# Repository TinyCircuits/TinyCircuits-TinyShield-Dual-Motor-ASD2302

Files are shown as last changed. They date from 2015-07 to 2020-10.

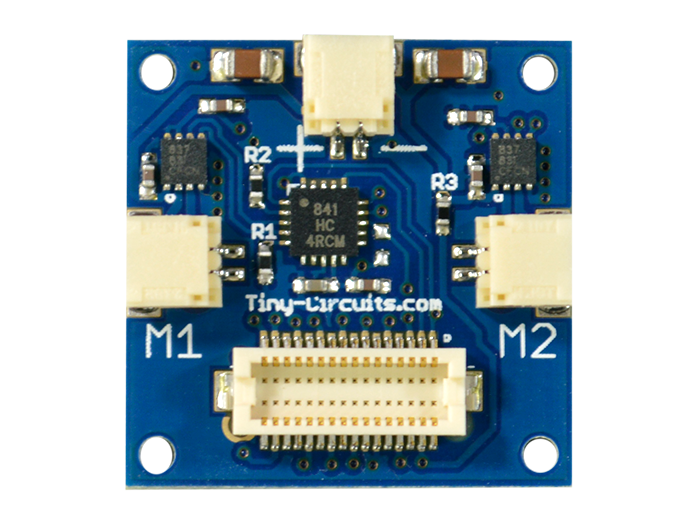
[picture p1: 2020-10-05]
images/ASD2302-R-Tutorial-Image-01.png

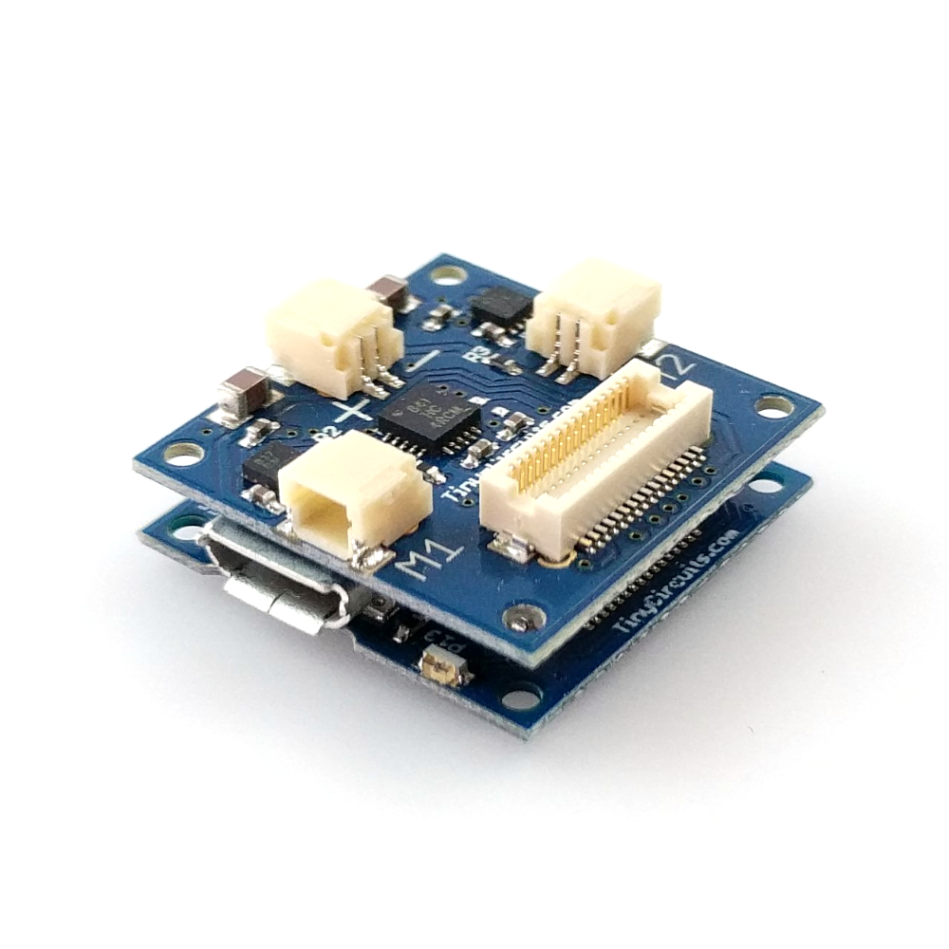
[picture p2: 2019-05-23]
images/ASD2302-R-Tutorial-Image-03.jpg

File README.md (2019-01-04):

# TinyCircuits TinyShield Dual Motor Board
# ASD2302 Rev3

The design files are located under design_files/ for the TinyCircuits ASD2302 Rev 3 PCB.  This is a TinyShield board (Square Version, 20mm x 20mm) that has a two TI DRV8847 motor drivers on it, to allow two DC brushed motors to be driven.

Format is in Cadsoft Eagle format - Eagle version 6.2 was used for the original design.

For more infomation on this, check out the product page at TinyCircuits.com:  https://tinycircuits.com/collections/motors/products/dual-motor-tinyshield

# License:

Design by TinyCircuits.
All design files are released under the Creative Commons Attribution Share-Alike 3.0 License, see the following link for details: http://creativecommons.org/licenses/by-sa/3.0

All text above must be included in any redistribution or derived design

This project uses designs and concepts developed as part of the Arduino project and the LilyPad project.  The TinyCircuits design files themselves (schematics, PCB and libraries) are not directly derived from these works' design files and have been created new, however the concepts and basic architecture behind the TinyDuino and TinyLily products are derived and we thank the hard work of the organizations below for their contributions to open-source hardware:
  
Original Arduino Uno Design by Team Arduino

LilyPad Arduino Design by Leah Buechley and Sparkfun Electronics

Please support the open-source hardware community

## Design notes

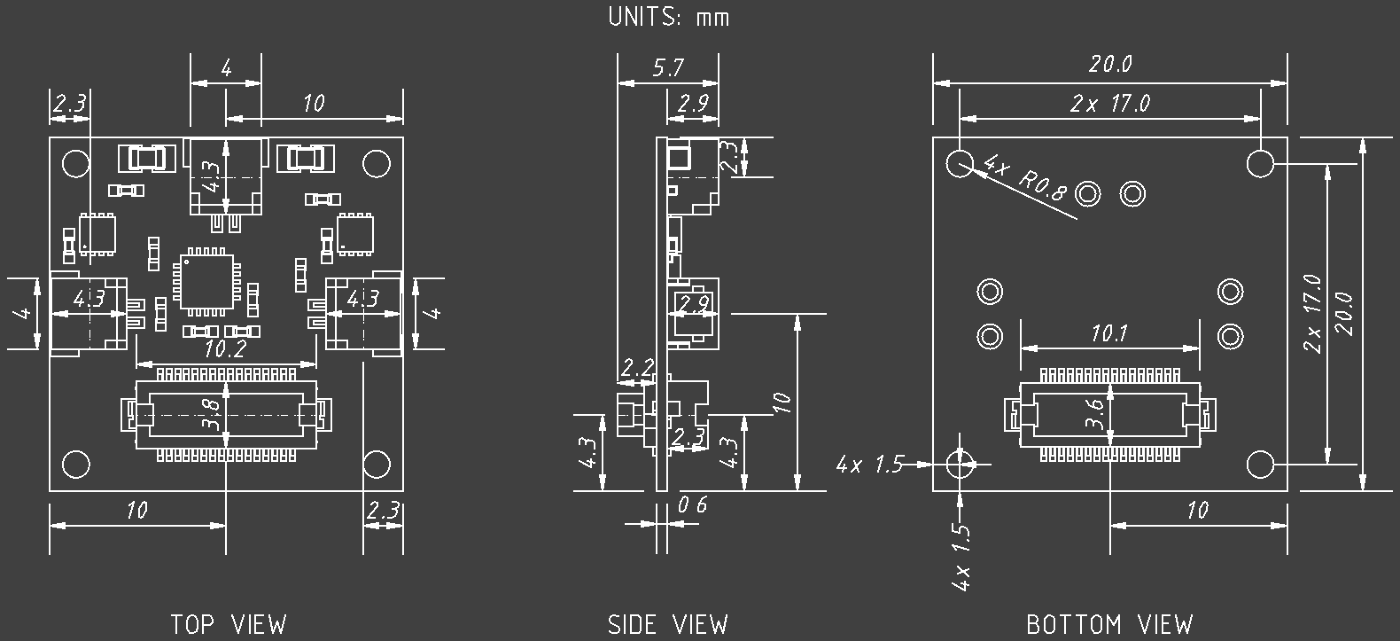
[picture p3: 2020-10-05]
cad/TinyShield_DUAL_MOTOR_ASD2302_REV3-DETAILED_DRAWING_COMPACT-PNG.png

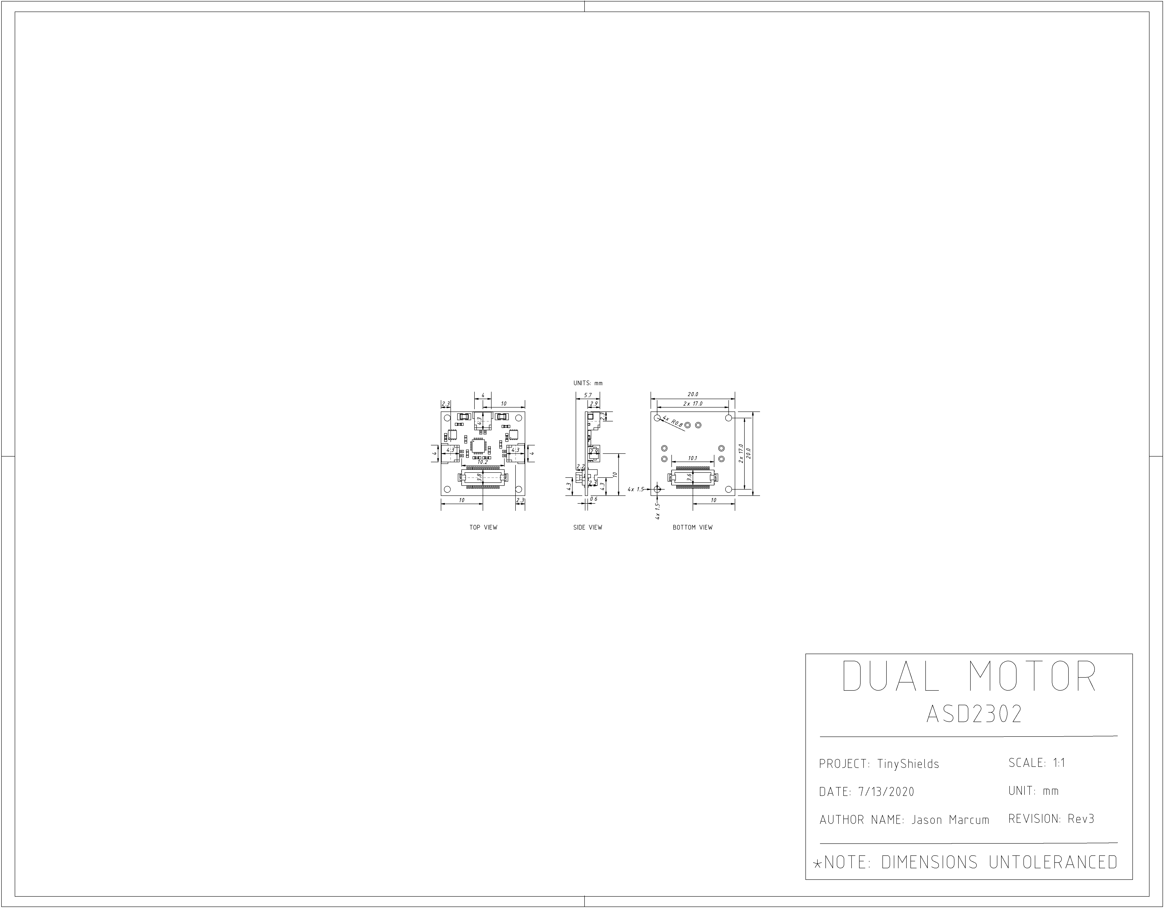
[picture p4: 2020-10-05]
cad/TinyShield_DUAL_MOTOR_ASD2302_REV3-DETAILED_DRAWING-PNG.png

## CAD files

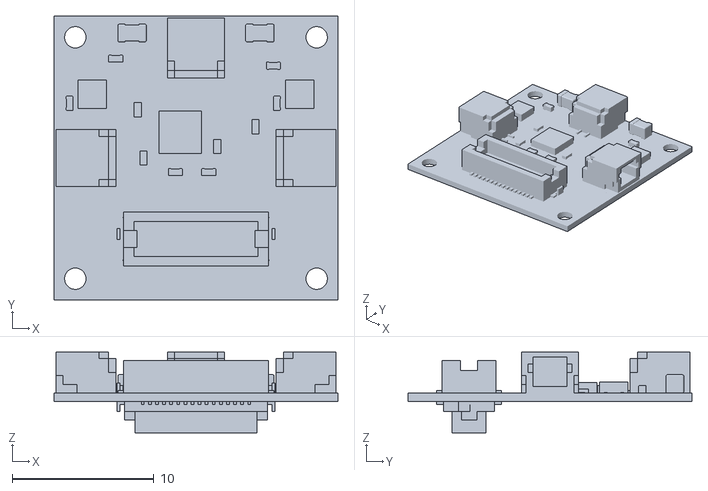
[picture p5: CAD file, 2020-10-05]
cad/TinyShield_MOTOR_STL_ASD2302_REV3-STL.stl
20.0 x 20.0 x 5.69

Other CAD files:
cad/TinyShield_DUAL_MOTOR_ASD2302_REV3-DETAILED_DRAWING-DXF.dxf

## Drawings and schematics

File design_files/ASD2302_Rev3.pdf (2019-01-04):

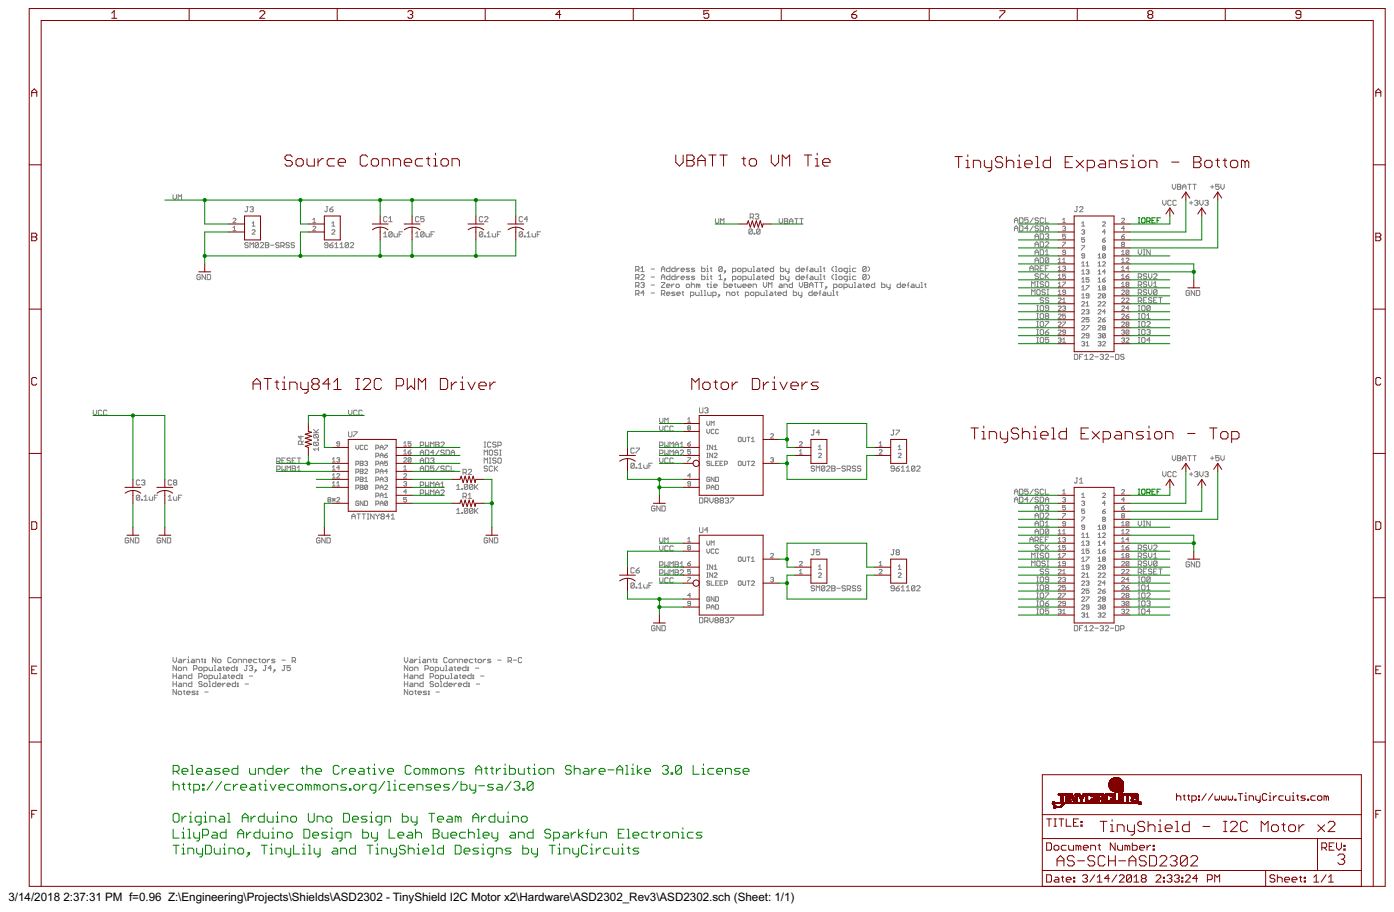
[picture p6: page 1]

3/14/2018 2:37:31 PM f=0.96 Z:\Engineering\Projects\Shields\ASD2302 - TinyShield I2C Motor x2\Hardware\ASD2302_Rev3\ASD2302.sch (Sheet: 1/1)

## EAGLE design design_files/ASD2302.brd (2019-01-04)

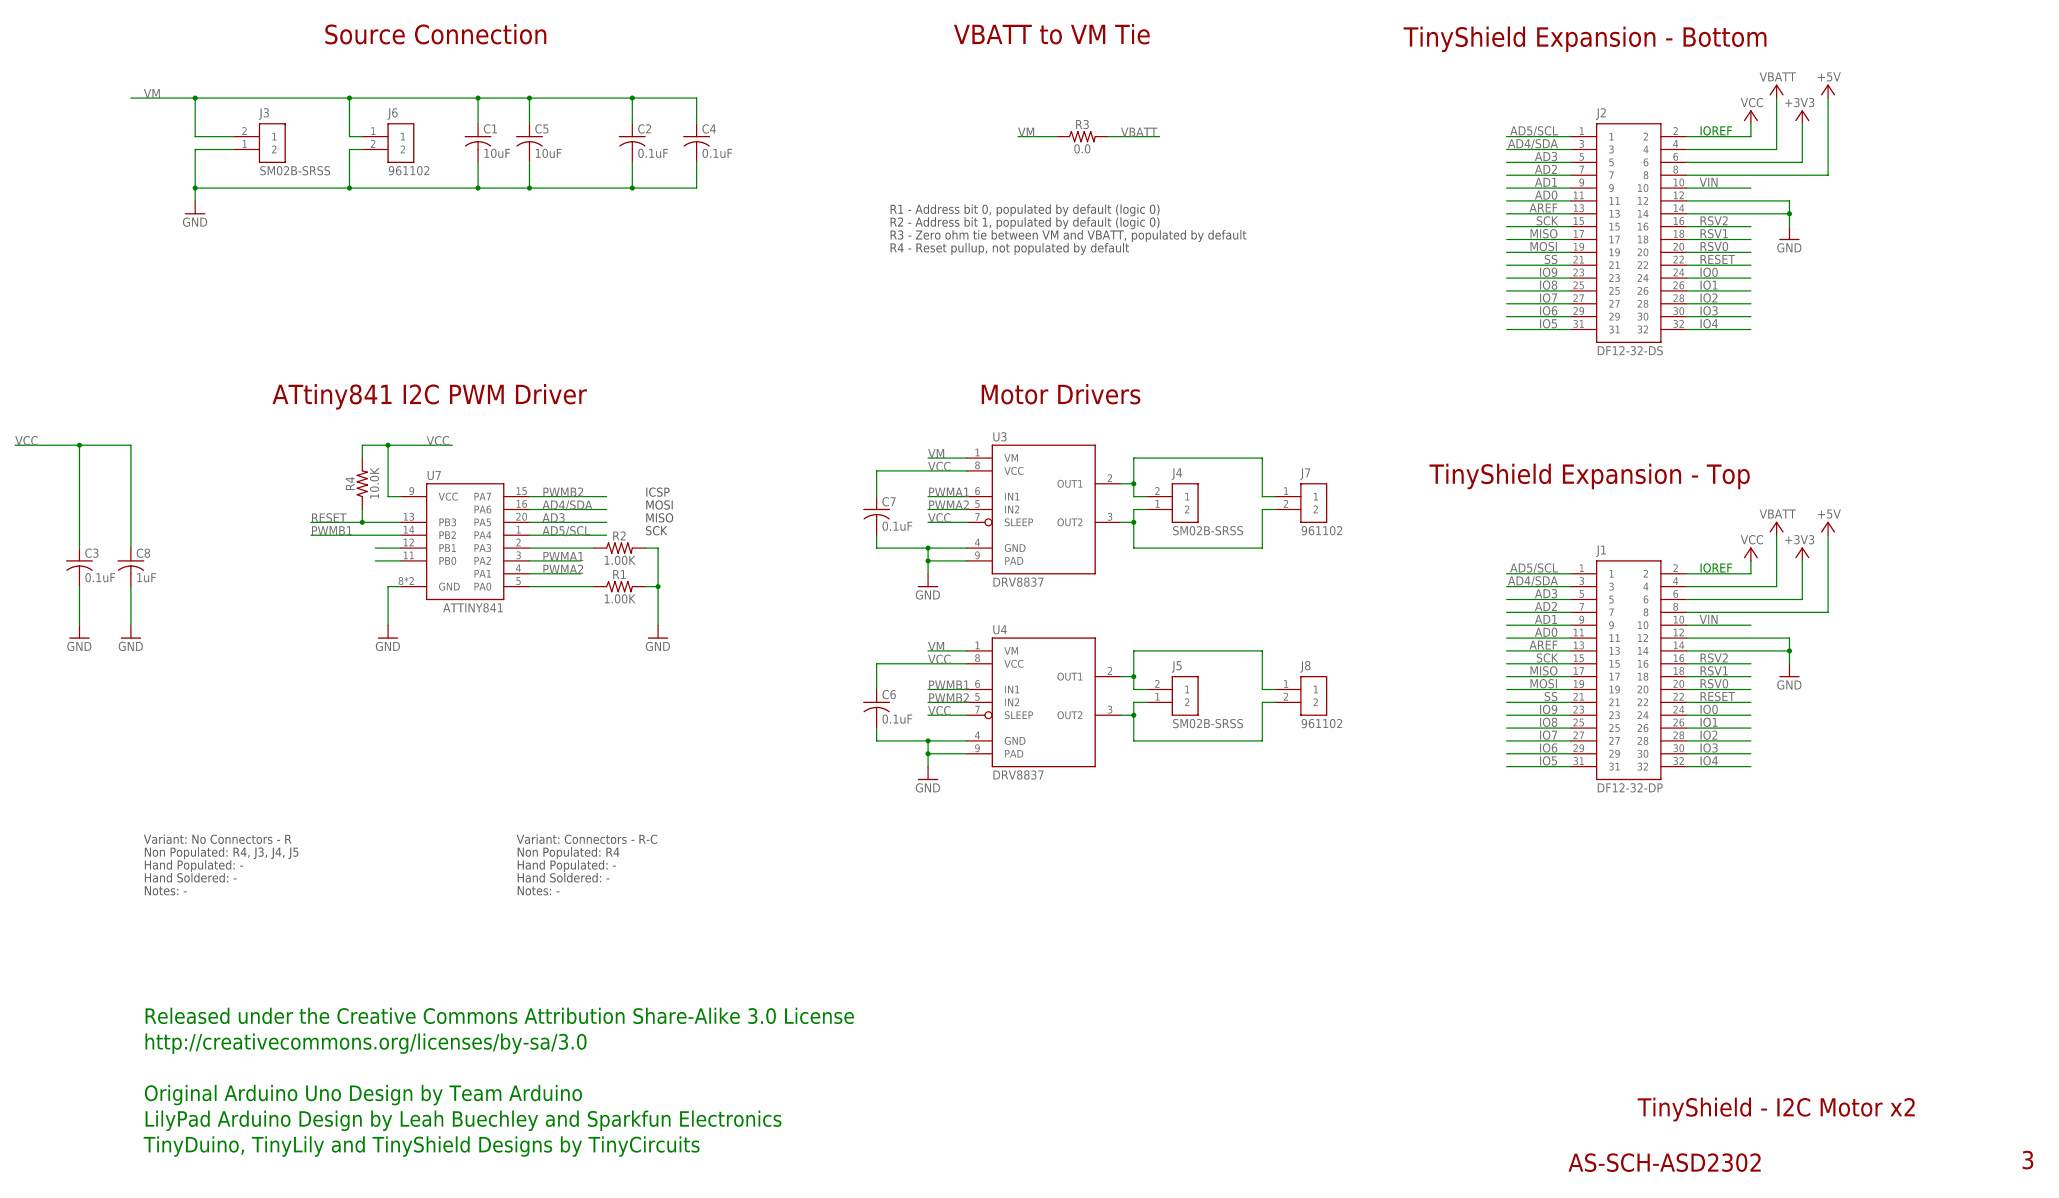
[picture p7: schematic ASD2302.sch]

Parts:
C1, C5: 10uF; C0805
C2: 0.1uF; C0402
C3, C4, C6, C7: 0.1uF; C0402; PARTNO AS-ITM-00008
C8: 1uF; C0402; PARTNO AS-ITM-00105
J1: DF12-32-DP; PARTNO AS-ITM-00015
J2: DF12-32-DS; PARTNO AS-ITM-00012
J3, J4, J5: SM02B-SRSS; JST_SH_2X1
J6, J7, J8: 961102; 2X.1"
R1, R2: 1.00K; 0402; PARTNO AS-ITM-00003
R3: 0.0; 0402
R4: 10.0K; 0402
U3, U4: DRV8837; WSON-8
U7: ATTINY841; VQFN-20

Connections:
+3V3: J1.6, J2.6
+5V: J1.8, J2.8
AD0: J1.11, J2.11
AD1: J1.9, J2.9
AD2: J1.7, J2.7
AD3: J1.5, J2.5, U7.20 (PA5)
AD4/SDA: J1.3, J2.3, U7.16 (PA6)
AD5/SCL: J1.1, J2.1, U7.1 (PA4)
AREF: J1.13, J2.13
GND: C1.2, C2.2, C3.2, C4.2, C5.2, C6.2, C7.2, C8.2, J1.12, J1.14, J2.12, J2.14, J3.1 (2), J6.2, R1.2, R2.2, U3.4 (GND), U3.9 (PAD), U4.4 (GND), U4.9 (PAD), U7.8 (GND), U7.PAD (GND)
IO0: J1.24, J2.24
IO1: J1.26, J2.26
IO2: J1.28, J2.28
IO3: J1.30, J2.30
IO4: J1.32, J2.32
IO5: J1.31, J2.31
IO6: J1.29, J2.29
IO7: J1.27, J2.27
IO8: J1.25, J2.25
IO9: J1.23, J2.23
MISO: J1.17, J2.17
MOSI: J1.19, J2.19
unnamed: J5.1 (2), J8.2, U4.3 (OUT2)
unnamed: J5.2 (1), J8.1, U4.2 (OUT1)
unnamed: J4.2 (1), J7.1, U3.2 (OUT1)
unnamed: J4.1 (2), J7.2, U3.3 (OUT2)
unnamed: R2.1, U7.2 (PA3)
unnamed: R1.1, U7.5 (PA0)
PWMA1: U3.6 (IN1), U7.3 (PA2)
PWMA2: U3.5 (IN2), U7.4 (PA1)
PWMB1: U4.6 (IN1), U7.14 (PB2)
PWMB2: U4.5 (IN2), U7.15 (PA7)
RESET: J1.22, J2.22, R4.1, U7.13 (PB3)
RSV0: J1.20, J2.20
RSV1: J1.18, J2.18
RSV2: J1.16, J2.16
SCK: J1.15, J2.15
SS: J1.21, J2.21
VBATT: J1.4, J2.4, R3.2
VCC: C3.1, C6.1, C7.1, C8.1, J1.2, J2.2, R4.2, U3.7 (SLEEP), U3.8 (VCC), U4.7 (SLEEP), U4.8 (VCC), U7.9 (VCC)
VIN: J1.10, J2.10
VM: C1.1, C2.1, C4.1, C5.1, J3.2 (1), J6.1, R3.1, U3.1 (VM), U4.1 (VM)

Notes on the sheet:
TinyShield Expansion - Bottom
TinyShield - I2C Motor x2
AS-SCH-ASD2302
TinyShield Expansion - Top
IOREF
Released under the Creative Commons Attribution Share-Alike 3.0 License
http://creativecommons.org/licenses/by-sa/3.0
LilyPad Arduino Design by Leah Buechley and Sparkfun Electronics
TinyDuino, TinyLily and TinyShield Designs by TinyCircuits
Original Arduino Uno Design by Team Arduino
ATtiny841 I2C PWM Driver
Motor Drivers
VBATT to VM Tie
Source Connection
MOSI
MISO
SCK
ICSP
R1 - Address bit 0, populated by default (logic 0)
R2 - Address bit 1, populated by default (logic 0)
R3 - Zero ohm tie between VM and VBATT, populated by default
R4 - Reset pullup, not populated by default
Non Populated: R4, J3, J4, J5
Hand Populated: -
Hand Soldered: -
Notes: -
Variant: No Connectors - R
Non Populated: R4
Variant: Connectors - R-C

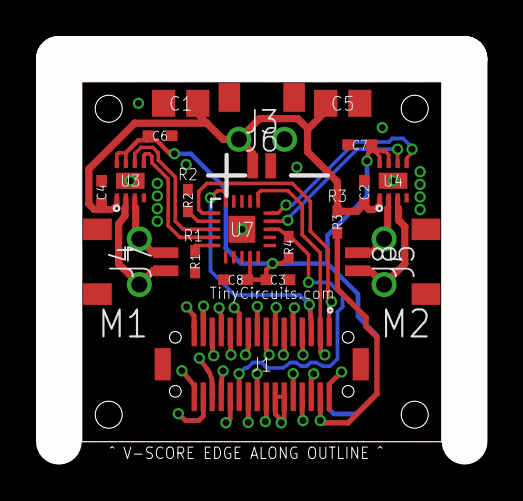
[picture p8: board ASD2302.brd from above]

Board: 2 copper layers, 20.0 x 20.0 mm, 24 parts (1 on the bottom side), 42 nets.

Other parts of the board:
U$1: DOCFIELD-TINYCIRCUITS-PCB

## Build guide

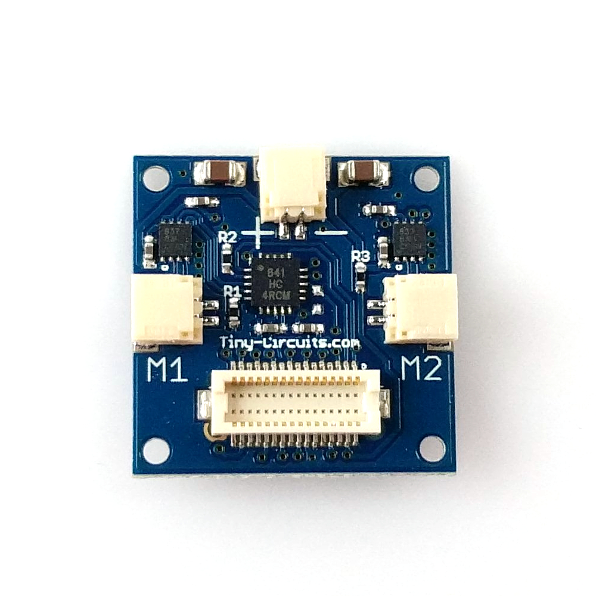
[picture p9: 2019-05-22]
images/ASD2302-R-Tutorial-Image-01.jpg

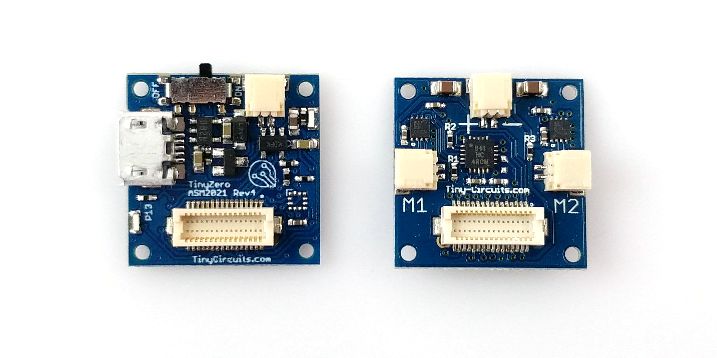
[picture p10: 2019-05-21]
images/ASD2302-R-Tutorial-Image-02.jpg

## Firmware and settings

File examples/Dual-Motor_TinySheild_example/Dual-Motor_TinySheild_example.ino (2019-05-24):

/*
  TinyCircuits Dual Motor Driver TinySheild Basic Example

  This example code shows basic usage of the ASD2302 Dual Motor Driver TinyShield.
  The library intance is created with the hardware address of the motor driver
  (up to 4 boards/8 motors) and then intialized with begin(maximum PWM value).
  The Dual Motor Driver has 16 bit PWM output capability, but keep in mind the
  output frequency is low when using a large timer value- great for some things,
  like driving servos. To drive the motors, use setMotor(motor, value) to set
  motor 1 or 2 to -maxPWM to +maxPWM.

  The board uses the ATtiny841 microcontroller and has direct register access-
  so just about any of the internal peripherals could be put to use.

  Written 30 July 2015
  By Ben Rose
  Modified 24 May 2019
  By Hunter Hykes

  https://TinyCircuits.com
*/

#include <Wire.h>
#include "MotorDriver.h"
//#define Serial SerialUSB
MotorDriver motor(2);//value passed is the address- remove resistor R1 for 1, R2 for 2, R1 and R2 for 3

int maxPWM = 10000;
int steps = 100;
int stepSize = maxPWM / steps;

void setup() {
  Serial.begin(9600);
  Wire.begin();
  //The value passed to begin() is the maximum PWM value, which is 16 bit(up to 65535)
  //This value also determines the output frequency- by default, 8MHz divided by the maxPWM value
  if (motor.begin(maxPWM)) {
    Serial.println("Motor driver not detected!");
    while (1);
  }
  //The failsafe turns off motors if a command is not sent in a certain amount of time.
  //Failsafe is set in milliseconds- comment or set to 0 to disable
  motor.setFailsafe(1000);
}

void loop() {
  int i;
  for (i = -maxPWM; i < maxPWM; i += stepSize) {
    delay(10);
    motor.setMotor(1, i);
    motor.setMotor(2, i);
  }
  for (i = maxPWM; i > -maxPWM; i -= stepSize) {
    delay(10);
    motor.setMotor(1, i);
    motor.setMotor(2, i);
  }
}

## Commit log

2019-01-04 Update format
    [ASD2302.brd, ASD2302.sch]
2020-07-28 Add CAD data
    [TinyShield_DUAL_MOTOR_ASD2302_REV3-DETAILED_DRAWING-DXF.dxf, TinyShield_MOTOR_STL_ASD2302_REV3-STL.stl]
2020-08-14 Update CAD drawing
    [TinyShield_DUAL_MOTOR_ASD2302_REV3-DETAILED_DRAWING-DXF.dxf]
